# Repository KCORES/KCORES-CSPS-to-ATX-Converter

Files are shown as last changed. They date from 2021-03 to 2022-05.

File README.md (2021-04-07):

# KCORES-CSPS-to-ATX-Converter

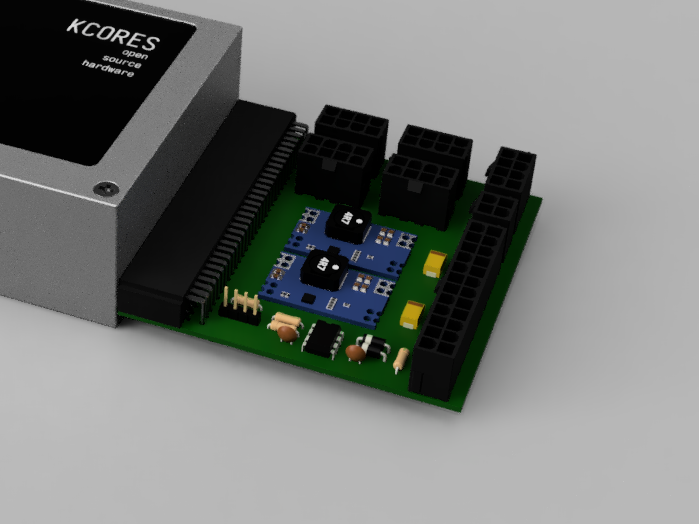
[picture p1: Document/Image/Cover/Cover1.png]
KCORES CSPS to ATX Converter


- 项目视频: [1元10瓦 垃圾佬的超级ATX电源-Youtube](https://www.youtube.com/watch?v=Dy0Jgn7Dg4A)
- KCORES 交流群: [826702309](https://jq.qq.com/?_wv=1027&k=jcr07ZYG)
- KCORES 官方网站: [KCORES.com](https://kcores.com/)
- 从零开始制作: [入门指南](Document/Getting_Started_Guide.md)

# Specification

| 12V | 5V | 3.3V  | 5VSB  |
|---|---|---|---|
|取决于CSPS| 5A | 5A | 5A |
| | 25W | 16.5W | 25W |

⚠: 5V 与 3.3V 不建议长期超过 4A 使用

## 模组接口
- 1x 24Pin 主板接口 (巨龙线序)
- 1x 4Pin IDE/SATA 硬盘接口 (联想线序)
- 5x 8Pin CPU/GPU 接口 (巨龙线序)
- 1x I2C PMBUS 控制接口

# Document

## Distinguish CSPS

KCORES CSPS to ATX Converter 可以用于引脚特征如下图所示的电源

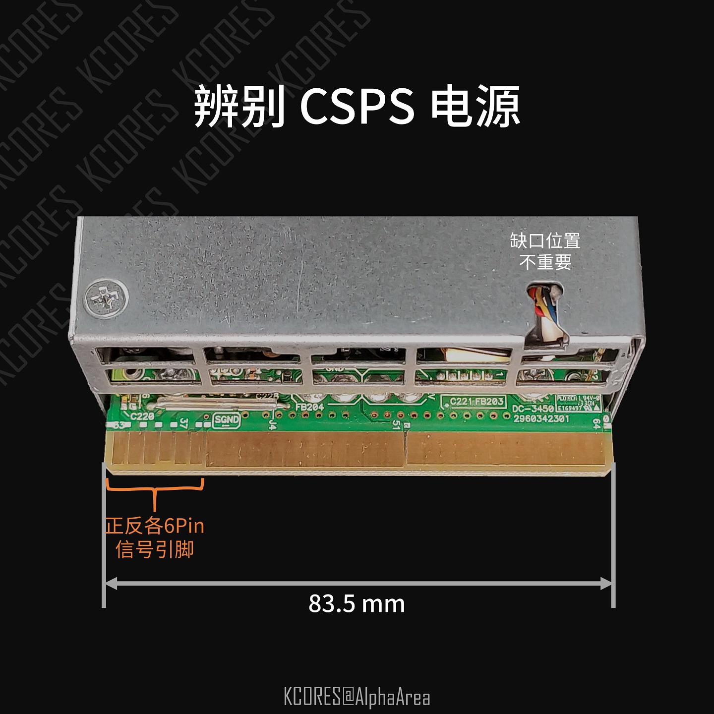
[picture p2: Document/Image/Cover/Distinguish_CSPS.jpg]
辨别 CSPS 电源


目前已知 Hewlett Packard Enterprise 与 Huawei 大量生产过 CSPS.  
不同厂家生产的 CSPS 可能外形略有不同, 但金手指必须与图示一致才可使用.  

## Getting Started Guide

- [入门指南](Document/Getting_Started_Guide.md)

# LICENSE

KCORES 许可证

# Contributor

- [@AlphaArea](https://github.com/alphaarea)
- @Ubiq
- [@karminski-牙医](https://github.com/karminski)
- [@MistyMoonR](https://github.com/MistyMoonR)

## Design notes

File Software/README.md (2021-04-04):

# Arduino Lib

# PC Host

[KCORES Link](https://github.com/KCORES/kcores-link)

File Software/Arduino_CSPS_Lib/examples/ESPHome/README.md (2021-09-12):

# ESPHome 集成

在 ESPHome 的 yaml 中增加

```yaml
esphome:
  # 原先内容
  includes:
    - CSPS/main.hpp
    - CSPS/KCORES_CSPS.h
    - CSPS/KCORES_CSPS.cpp
```

创建文件夹 `CSPS` 将 `main.hpp`, `KCORES_CSPS.h` 以及 `KCORES_CSPS.cpp` 丢进去

## 增加传感器

使用自定义传感器获取数据

```yaml
sensor:
  - platform: custom
    lambda: |-
      auto power = new CSPSPower();
      App.register_component(power);
      return {power->fan_speed, power->temp1, power->temp2, power->power_out, power->power_in, power->current_out, power->current_in, power->voltage_out, power->voltage_in};

    sensors:
    - name: "Fan Speed"
      accuracy_decimals: 0
      unit_of_measurement: RPM
    - name: "Temp 1"
      accuracy_decimals: 1
      unit_of_measurement: °C
    - name: "Temp 2"
      accuracy_decimals: 1
      unit_of_measurement: °C
    - name: "Power Out"
      accuracy_decimals: 0
      unit_of_measurement: W
    - name: "Power In"
      accuracy_decimals: 0
      unit_of_measurement: W
    - name: "Current Out"
      accuracy_decimals: 1
      unit_of_measurement: A
    - name: "Current In"
      accuracy_decimals: 1
      unit_of_measurement: A
    - name: "Voltage Out"
      accuracy_decimals: 1
      unit_of_measurement: V
    - name: "Voltage In"
      accuracy_decimals: 1
      unit_of_measurement: V
```

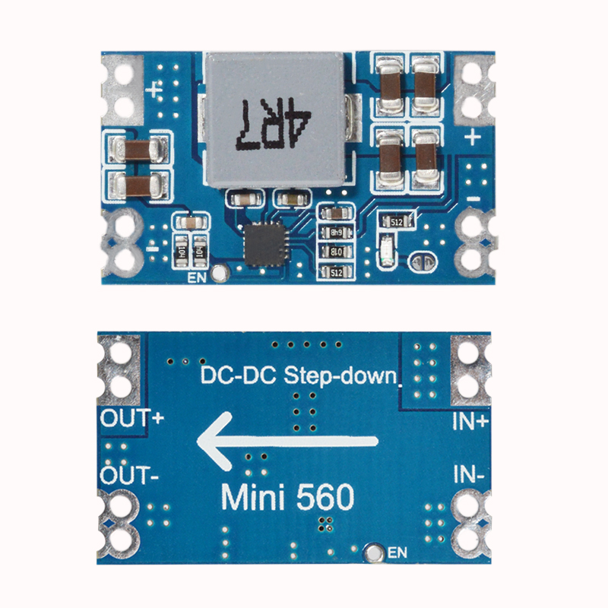
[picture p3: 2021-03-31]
Document/Datasheet/Mini 560/Mini 560.jpg

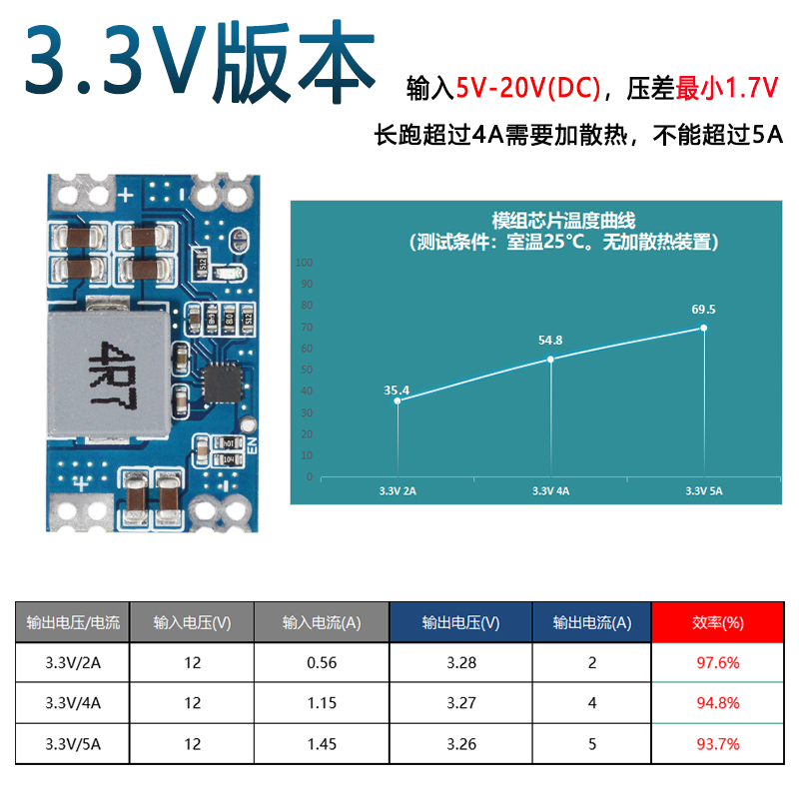
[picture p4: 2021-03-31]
Document/Datasheet/Mini 560/3.3V.jpg

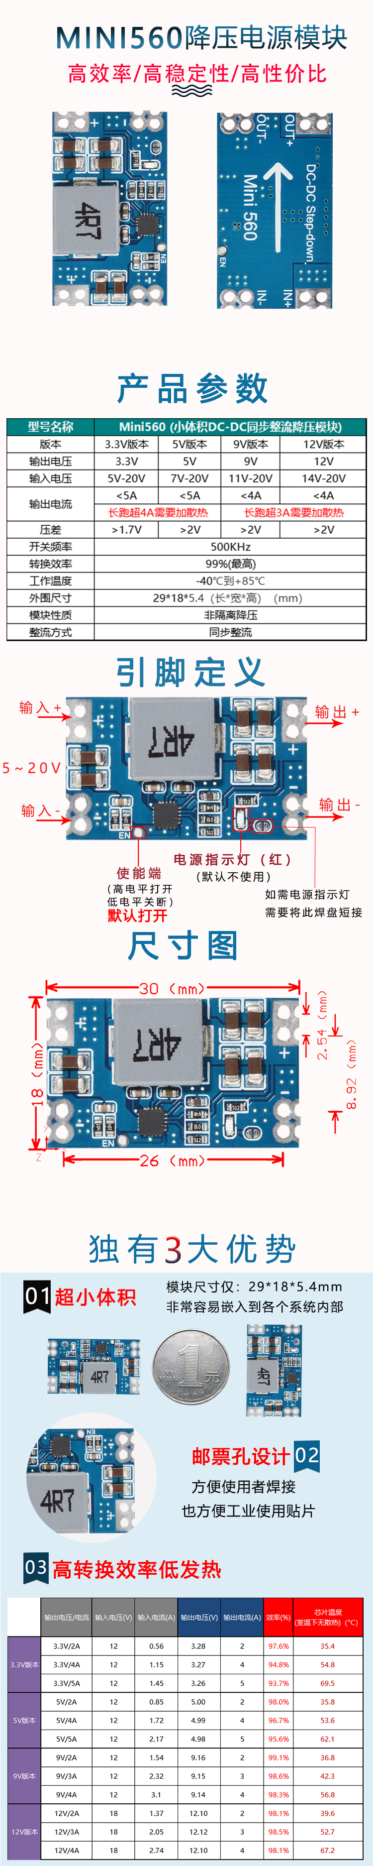
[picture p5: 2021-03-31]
Document/Datasheet/Mini 560/Mini 560-1.jpg

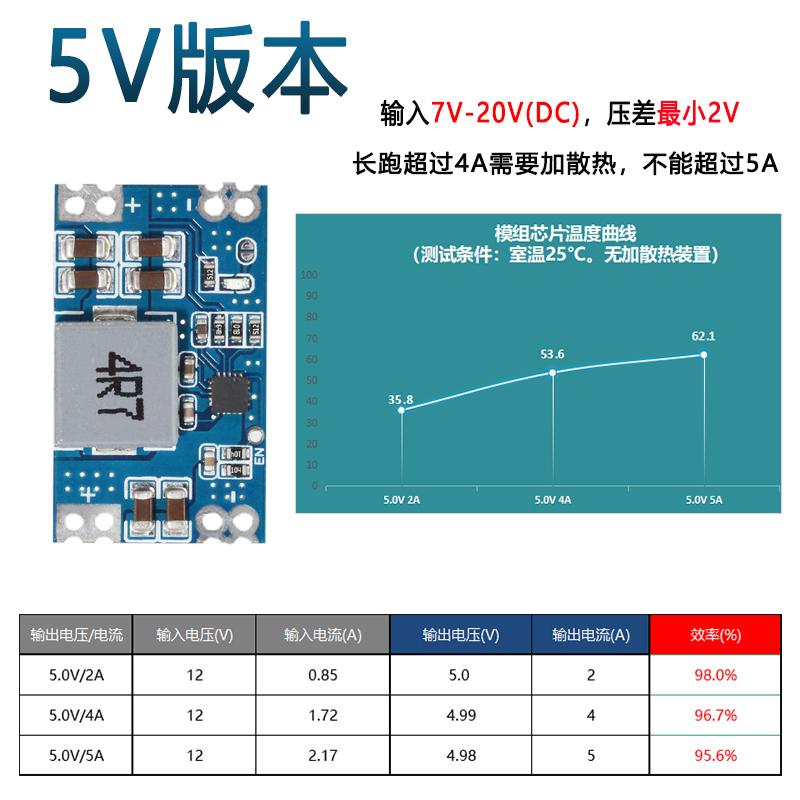
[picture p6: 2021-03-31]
Document/Datasheet/Mini 560/5V.jpg

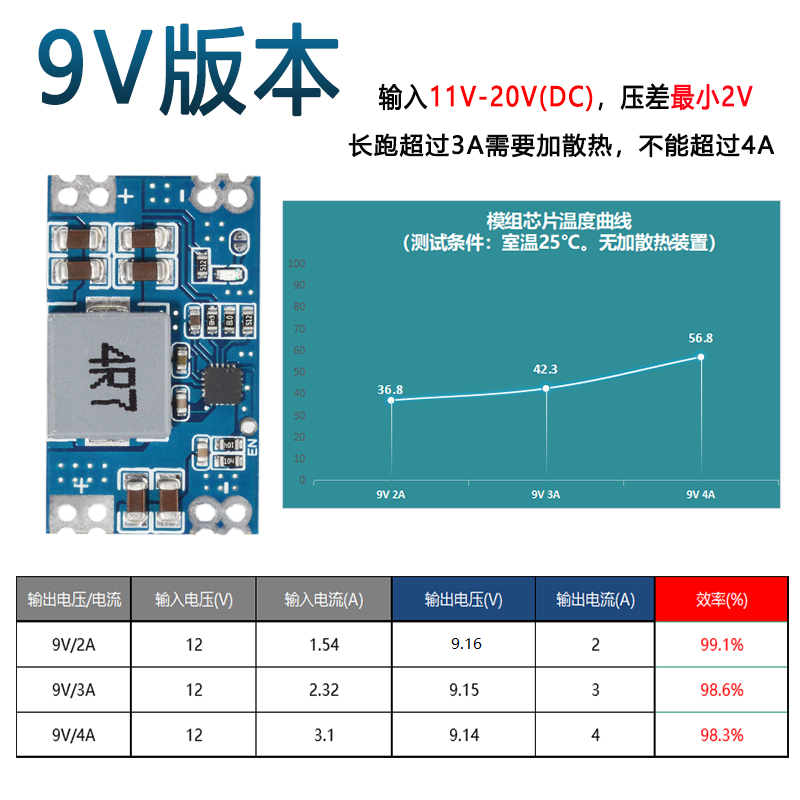
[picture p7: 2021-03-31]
Document/Datasheet/Mini 560/9V.jpg

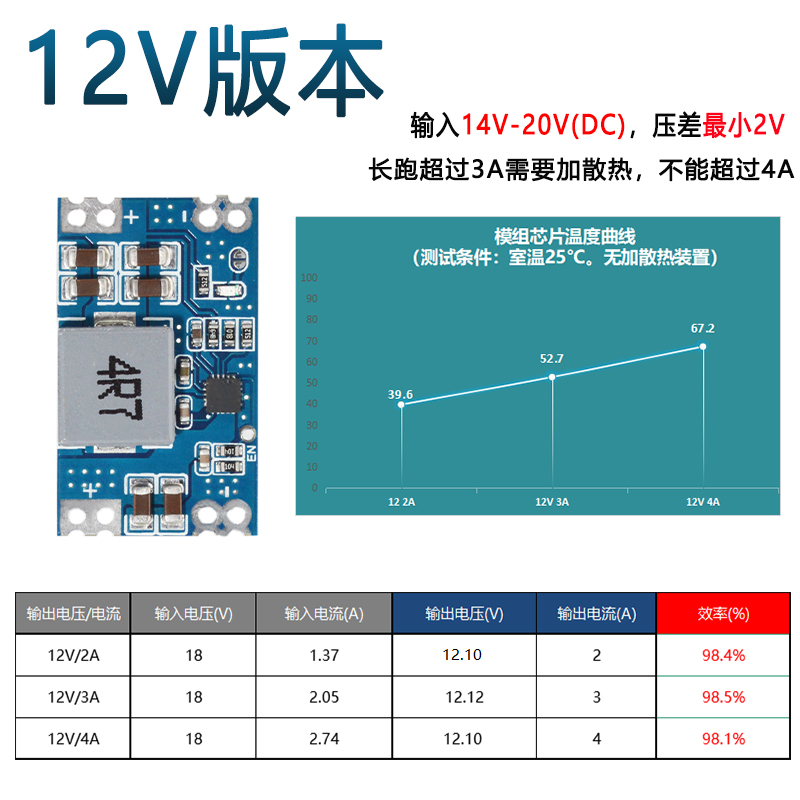
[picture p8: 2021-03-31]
Document/Datasheet/Mini 560/12V.jpg

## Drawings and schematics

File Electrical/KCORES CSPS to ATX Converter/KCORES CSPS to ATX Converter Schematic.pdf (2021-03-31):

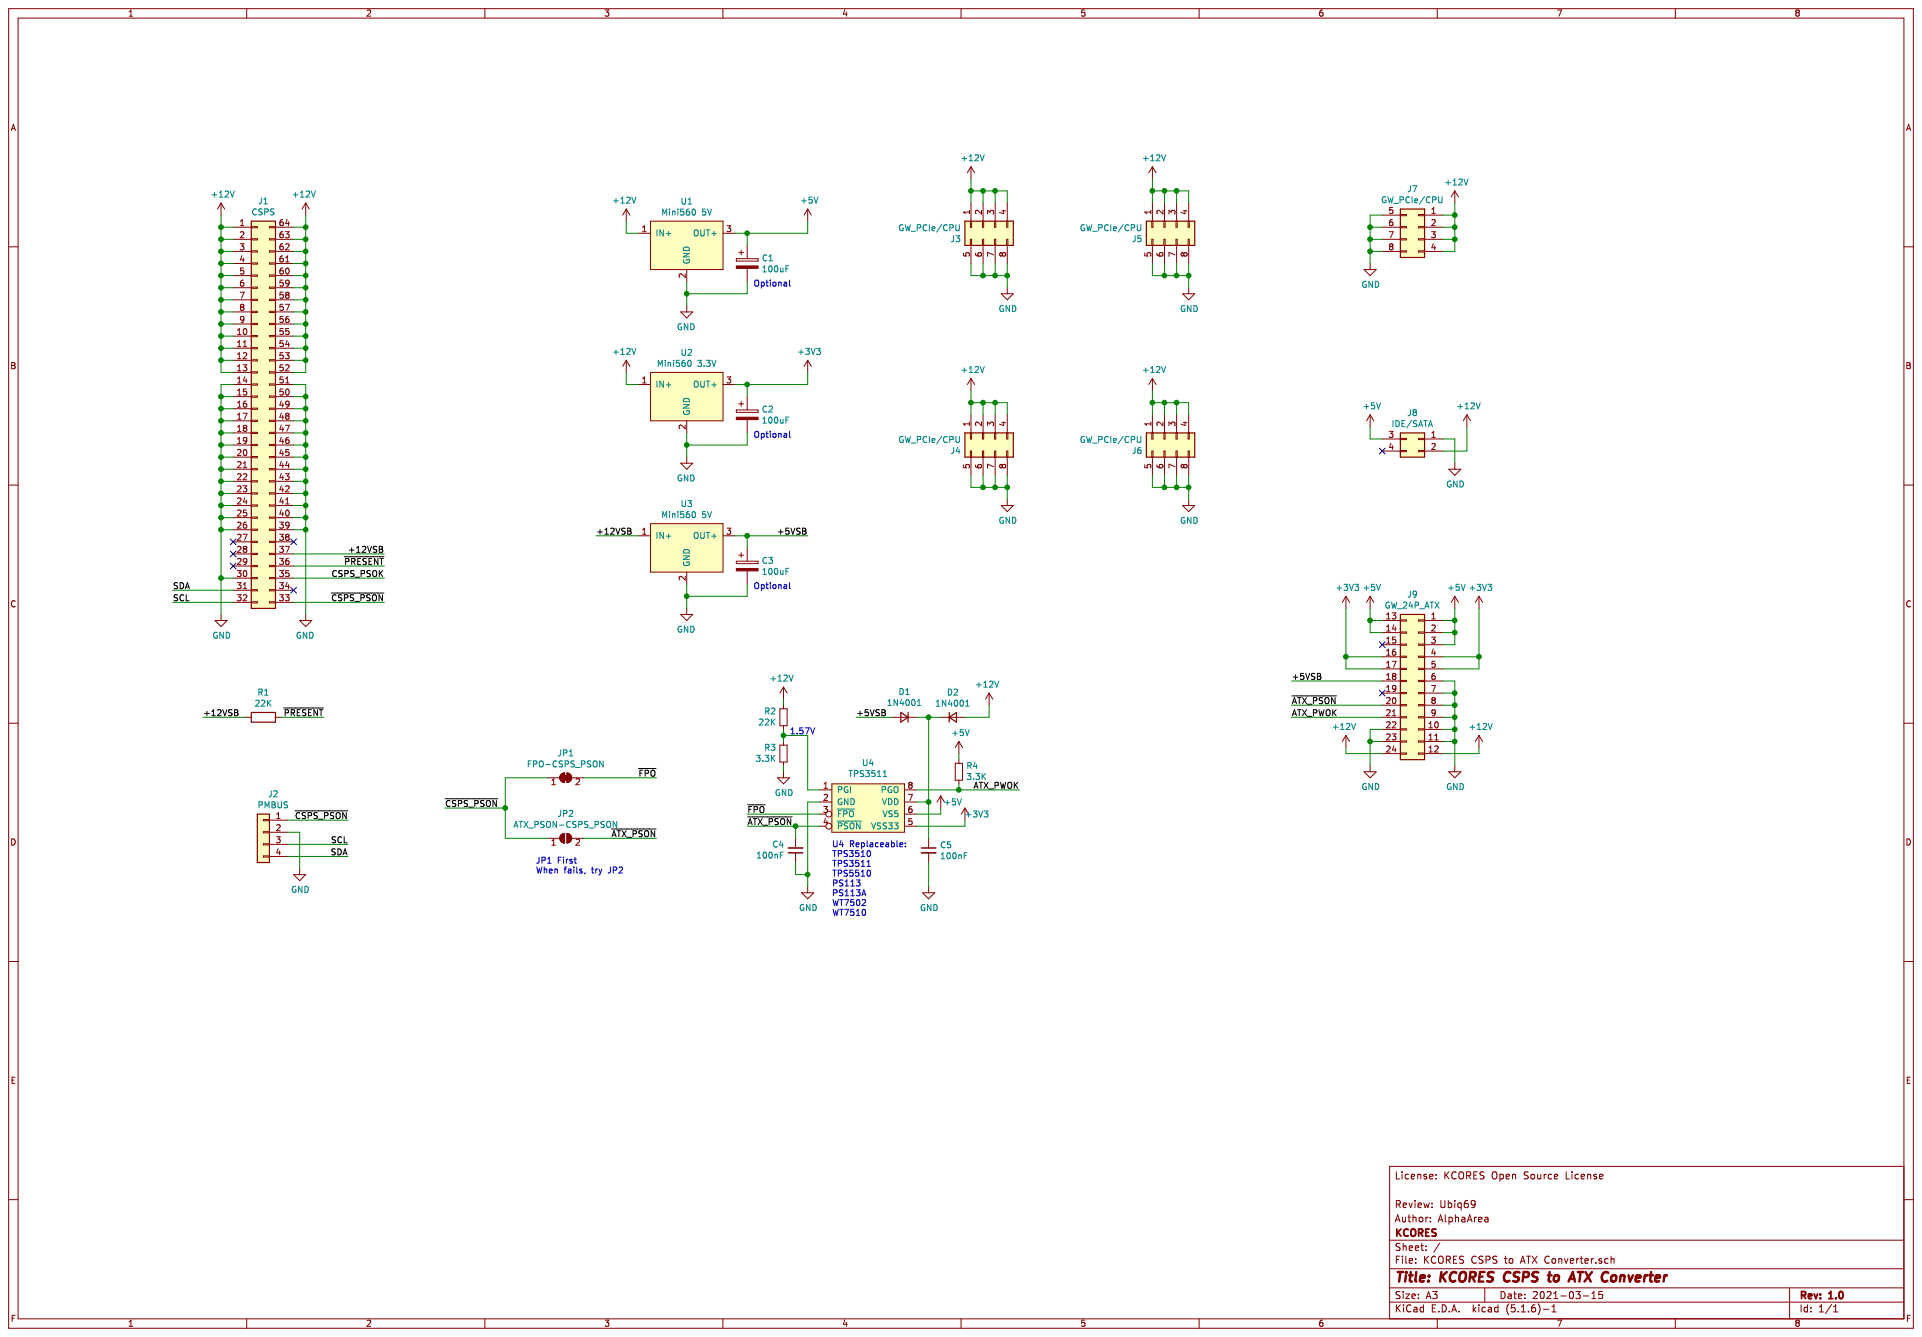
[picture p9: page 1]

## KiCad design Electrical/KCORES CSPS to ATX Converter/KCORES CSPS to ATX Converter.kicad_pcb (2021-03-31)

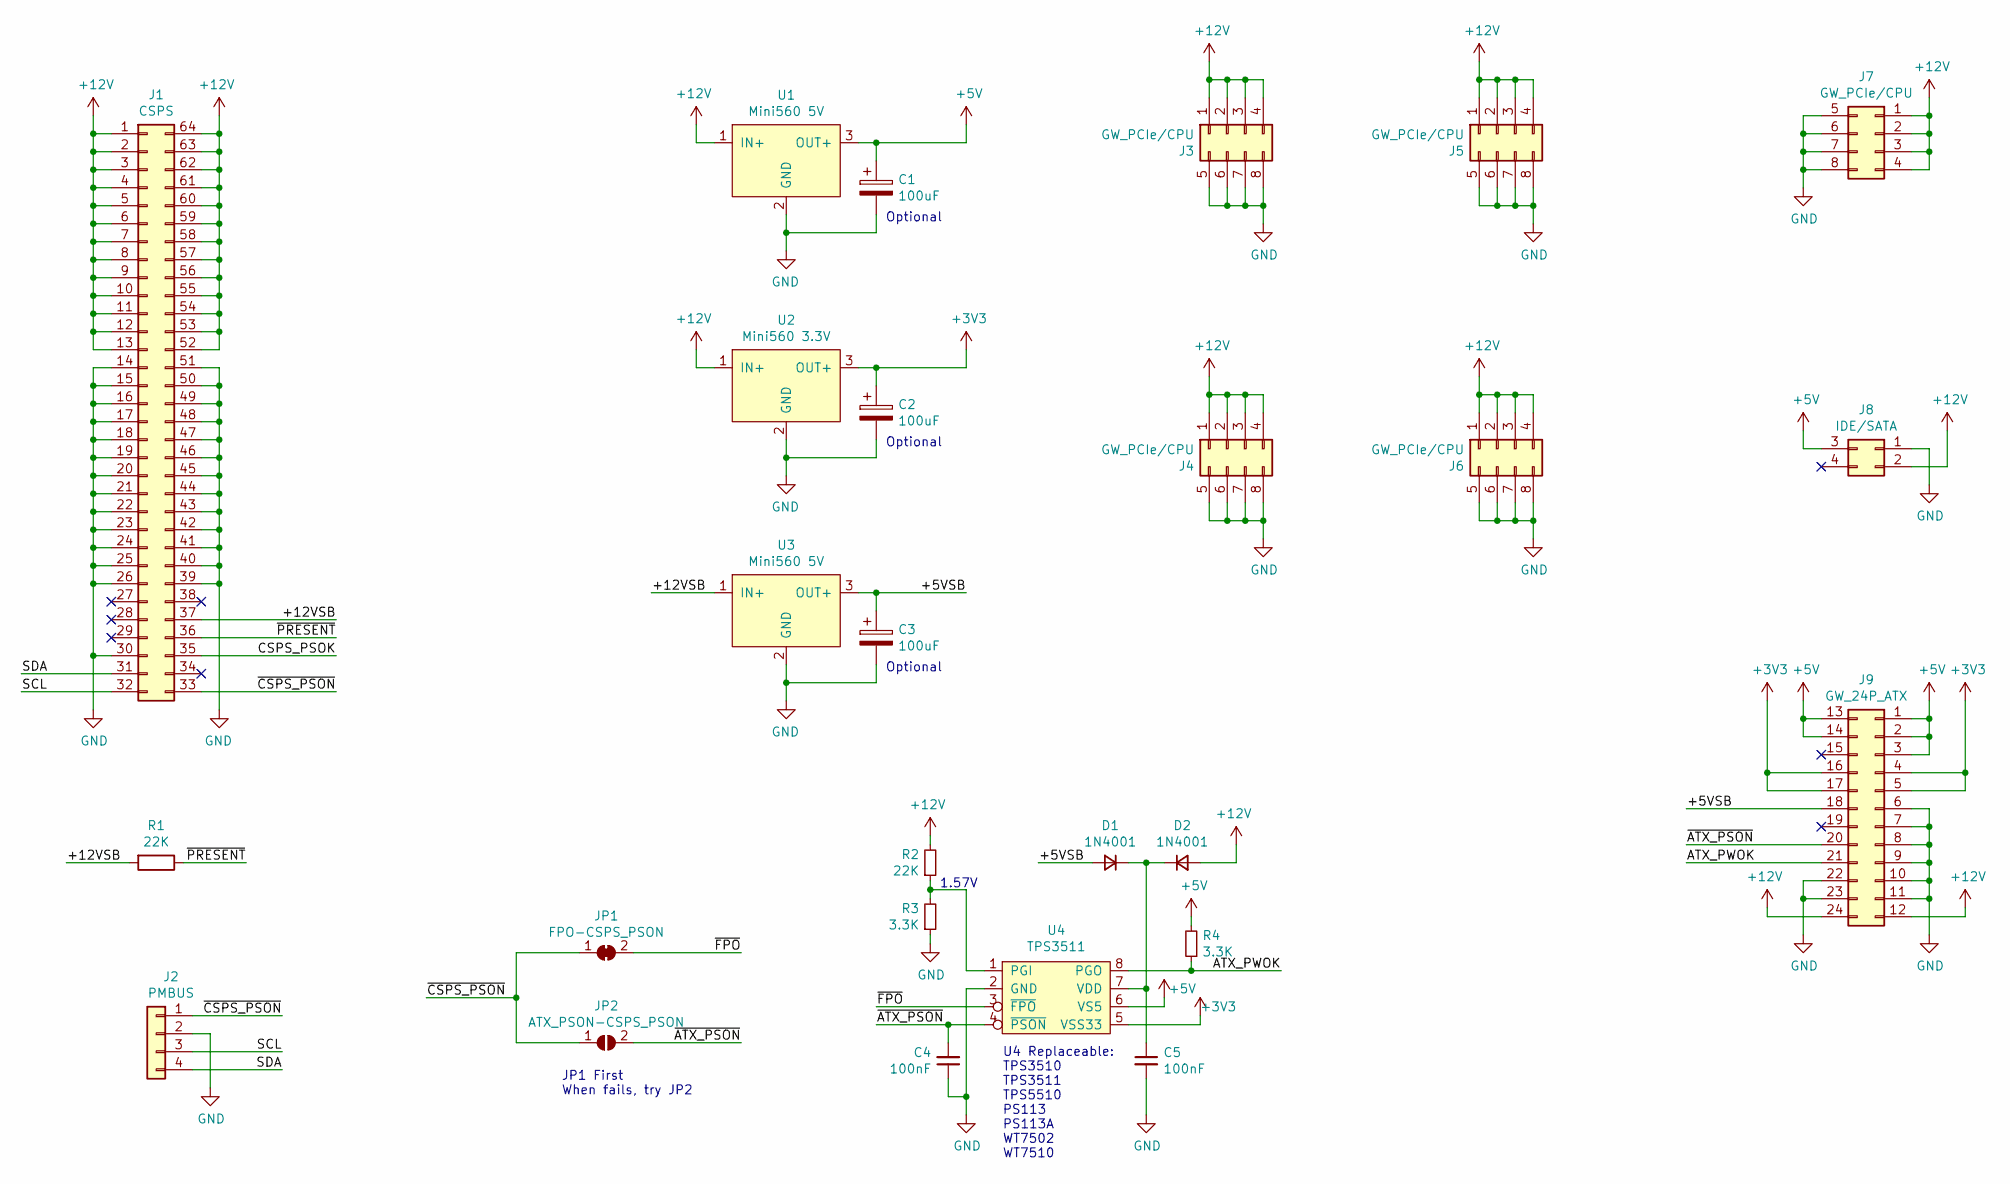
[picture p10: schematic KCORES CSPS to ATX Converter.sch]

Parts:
C1, C2, C3: 100uF; CP_EIA-7343-31_Kemet-D_Pad2.25x2.55mm_HandSolder
C4, C5: 100nF; C_Disc_D5.0mm_W2.5mm_P2.50mm
D1, D2: 1N4001; D_DO-41_SOD81_P7.62mm_Horizontal
J1: CSPS; CSPS_64P_2.54mm
J2: PMBUS; PinHeader_1x04_P2.54mm_Vertical
J3, J4, J5, J6, J7: GW_PCIe/CPU; ATX_8Pin_P4.20mm_Vertical_4.20mm
J8: IDE/SATA; ATX_4Pin_P4.20mm_Vertical_4.20mm
J9: GW_24P_ATX; ATX_24Pin_P4.20mm_Vertical_4.20mm
JP1: FPO-CSPS_PSON; SolderJumper-2_P1.3mm_Bridged_RoundedPad1.0x1.5mm
JP2: ATX_PSON-CSPS_PSON; SolderJumper-2_P1.3mm_Open_RoundedPad1.0x1.5mm
R1, R2: 22K; R_Axial_DIN0207_L6.3mm_D2.5mm_P7.62mm_Horizontal
R3, R4: 3.3K; R_Axial_DIN0207_L6.3mm_D2.5mm_P7.62mm_Horizontal
U1, U3: Mini560 5V; Converter_DCDC_Mini_560
U2: Mini560 3.3V; Converter_DCDC_Mini_560
U4: TPS3511; DIP-8_W7.62mm

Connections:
+3V3: C2.1, J9.4, J9.5, J9.16, J9.17, U2.3 (OUT+), U4.5 (VSS33)
+5V: C1.1, J8.3, J9.1, J9.2, J9.3, J9.13, J9.14, R4.2, U1.3 (OUT+), U4.6 (VS5)
+12V: D2.2 (A), J1.1, J1.2, J1.3, J1.4, J1.5, J1.6, J1.7, J1.8, J1.9, J1.10, J1.11, J1.12, J1.13, J1.52, J1.53, J1.54, J1.55, J1.56, J1.57, J1.58, J1.59, J1.60, J1.61, J1.62, J1.63, J1.64, J3.1, J3.2, J3.3, J3.4, J4.1, J4.2, J4.3, J4.4, J5.1, J5.2, J5.3, J5.4, J6.1, J6.2, J6.3, J6.4, J7.1, J7.2, J7.3, J7.4, J8.2, J9.12, J9.24, R2.2, U1.1 (IN+), U2.1 (IN+)
/+5VSB: C3.1, D1.2 (A), J9.18, U3.3 (OUT+)
/+12VSB: J1.37, R1.2, U3.1 (IN+)
/ATX_PWOK: J9.21, R4.1, U4.8 (PGO)
/CSPS_PSOK: J1.35
/SCL: J1.32, J2.3
/SDA: J1.31, J2.4
/~ATX_PSON: C4.2, J9.20, JP2.2 (B), U4.4 (~PSON)
/~CSPS_PSON: J1.33, J2.1, JP1.1 (A), JP2.1 (A)
/~FPO: JP1.2 (B), U4.3 (~FPO)
/~PRESENT: J1.36, R1.1
GND: C1.2, C2.2, C3.2, C4.1, C5.2, J1.14, J1.15, J1.16, J1.17, J1.18, J1.19, J1.20, J1.21, J1.22, J1.23, J1.24, J1.25, J1.26, J1.30, J1.39, J1.40, J1.41, J1.42, J1.43, J1.44, J1.45, J1.46, J1.47, J1.48, J1.49, J1.50, J1.51, J2.2, J3.5, J3.6, J3.7, J3.8, J4.5, J4.6, J4.7, J4.8, J5.5, J5.6, J5.7, J5.8, J6.5, J6.6, J6.7, J6.8, J7.5, J7.6, J7.7, J7.8, J8.1, J9.6, J9.7, J9.8, J9.9, J9.10, J9.11, J9.22, J9.23, R3.1, U1.2 (GND), U2.2 (GND), U3.2 (GND), U4.2 (GND)
unnamed: C5.1, D1.1 (K), D2.1 (K), U4.7 (VDD)
unnamed: R2.1, R3.2, U4.1 (PGI)

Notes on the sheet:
Optional
1.57V
JP1 First When fails, try JP2
U4 Replaceable: TPS3510 TPS3511 TPS5510 PS113 PS113A WT7502 WT7510

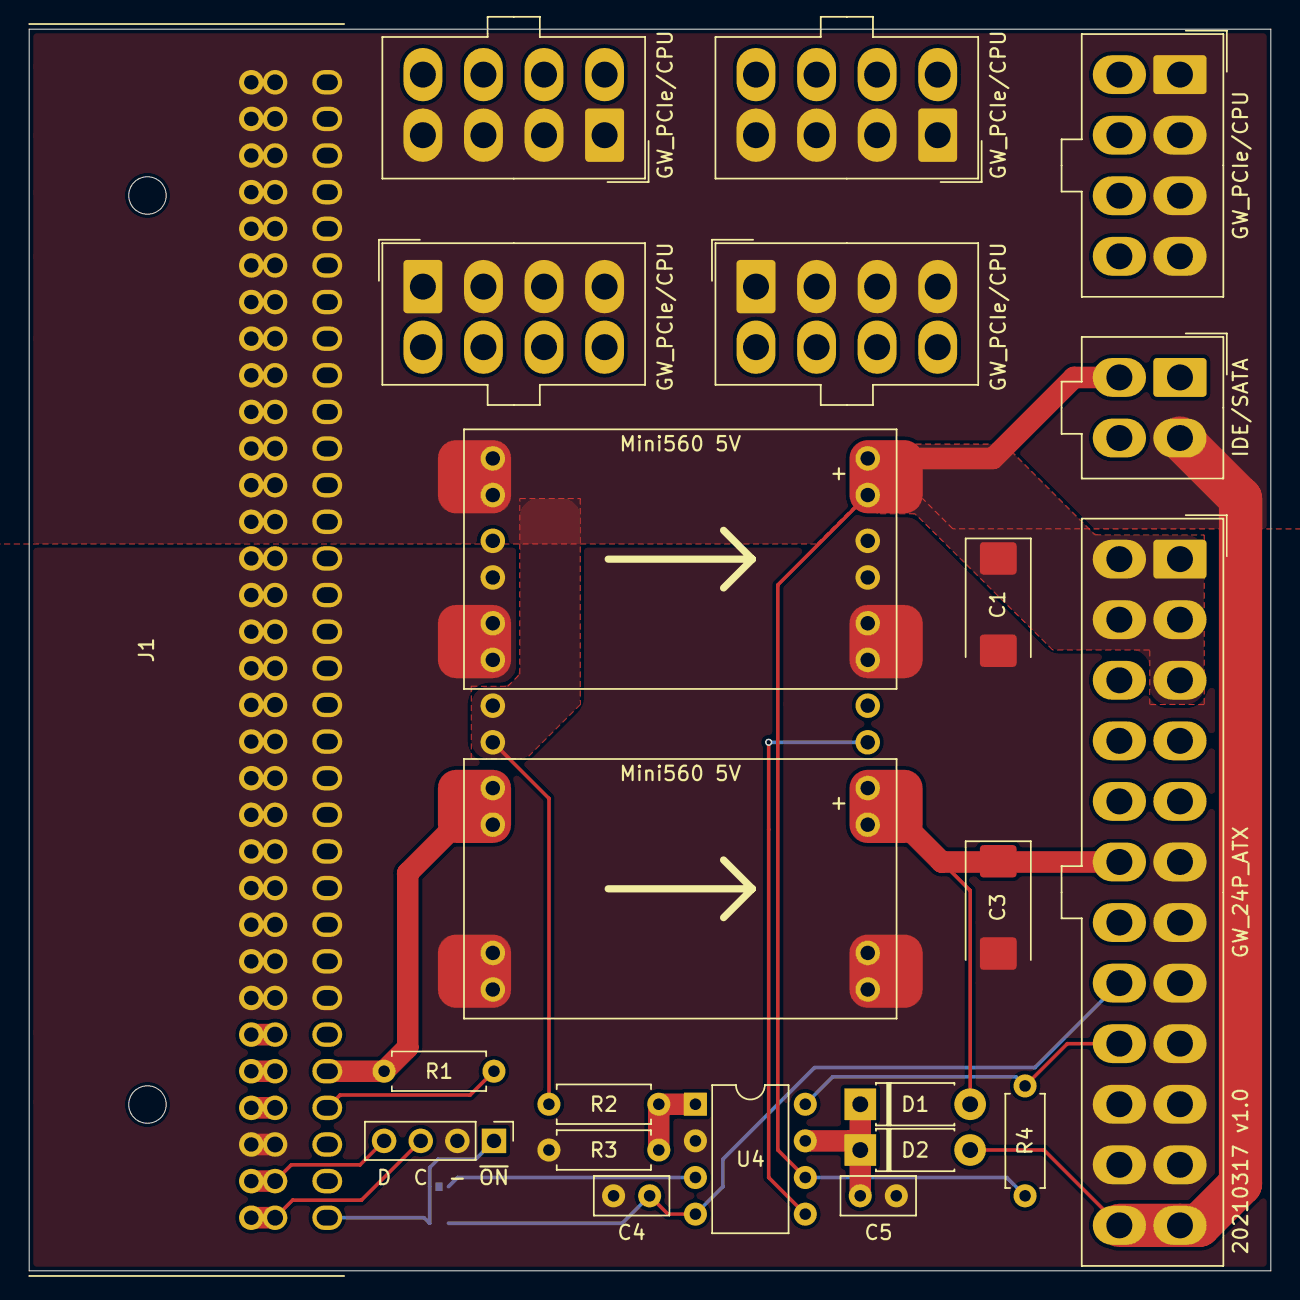
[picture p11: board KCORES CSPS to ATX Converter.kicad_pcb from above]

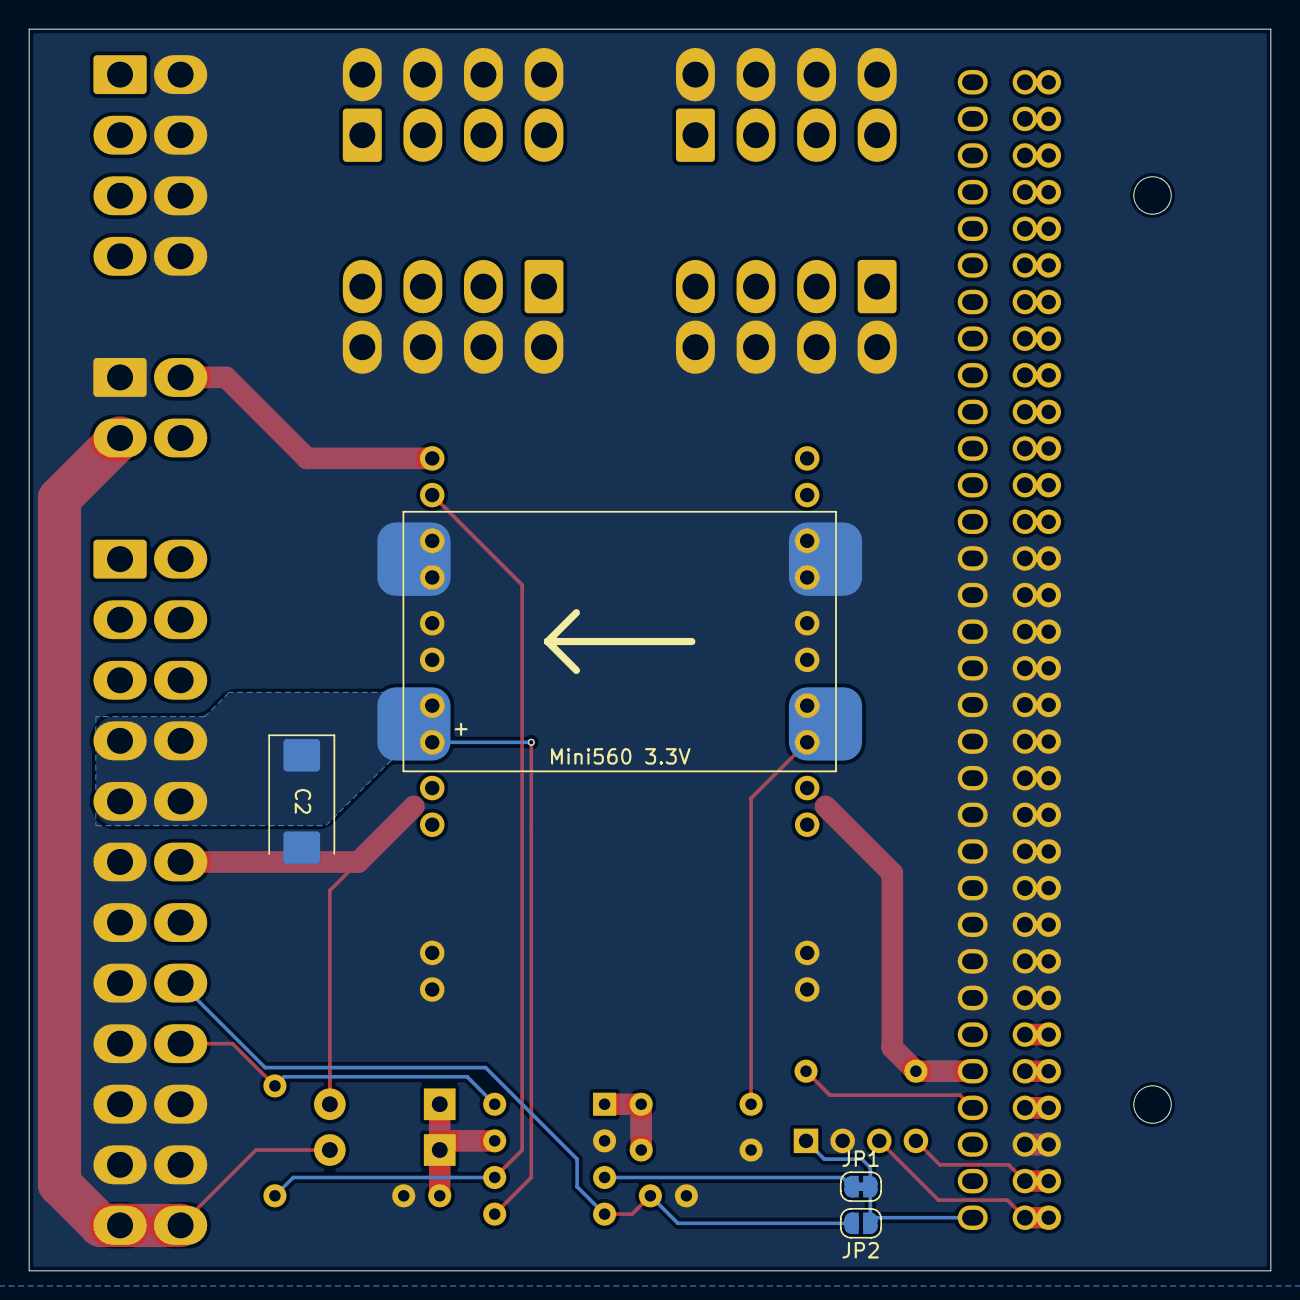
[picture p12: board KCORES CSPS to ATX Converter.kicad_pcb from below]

Board: 2 copper layers, 86.1 x 86.1 mm, 26 parts (4 on the bottom side), 15 nets.

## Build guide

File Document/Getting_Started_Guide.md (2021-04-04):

# 准备

1. 下载 [Releases](https://github.com/KCORES/KCORES-CSPS-to-ATX-Converter/releases) 中最新发布版的 Gerber 文件包与 BOM 表格.  
    - Gerber 文件: 用于发送给 PCB 工厂生产 PCB
    - BOM 表格: 购买元器件

## BOM 说明

1. 钽电容选配, 不焊接钽电容不影响转接板性能
2. 5566 连接器 (ATX 插座) 分实心针与空心针两种，互不兼容, 本项目全部使用实心针
3. Mini560 模块上没有电压标注, 保留包装，切勿弄混
4. 支持两种 CSPS 连接器
    - FCI 10053363-200LF: 进口连接器, 价格较贵, 允许通过较大电流, 插拔手感较好
    - WingTAT S-64M-2.54-5: 廉价连接器, 仅建议搭配 460W 与 750W 电源时使用
5. U4 监控芯片有多种替换件, 建议选择 TPS3510P

## 安全注意

- 不要随意拆开 CSPS 外壳, 即使断电后 PFC 电容内可能仍有高压
- 禁止带电插拔 CSPS 与转接板, 必须先断开市电, 待 CSPS 风扇停转后再插拔转接板

# 焊接

## 焊接一

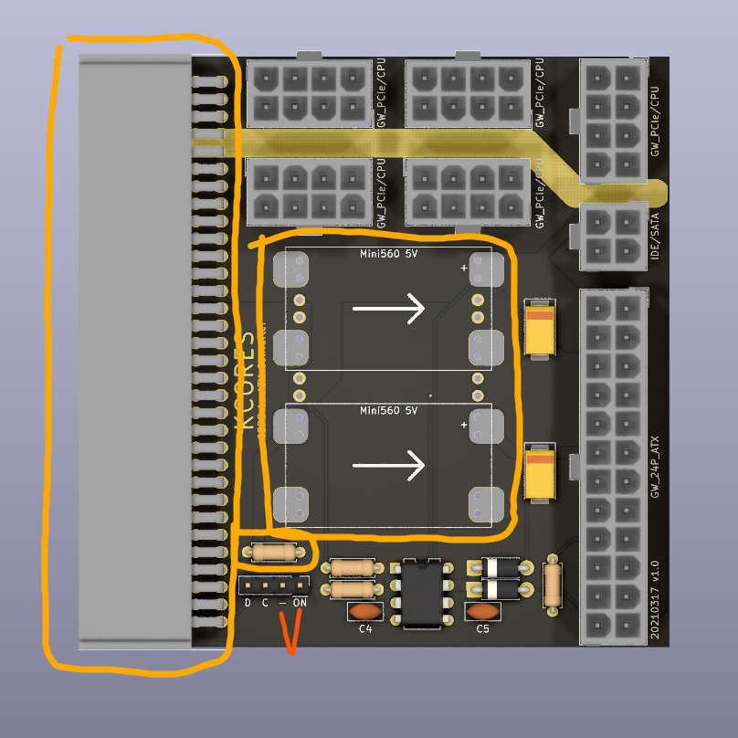
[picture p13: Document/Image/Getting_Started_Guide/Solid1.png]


- CSPS 连接器
- 所有降压模块
- R1 识别电阻

完成焊接后, 插入电源并通电, 短接橙色线画出的 GND 与 ~ON 引脚开机, CSPS 尾部电源指示灯变绿, 使用万用表测量各输出口电压是否正常

- 若无 12V 输出, 请检查主输出是否短路, R1 识别电阻是否焊接错误
- 若无 5V/3.3V 输出, 请检查对应的 DCDC 模块

## 焊接二

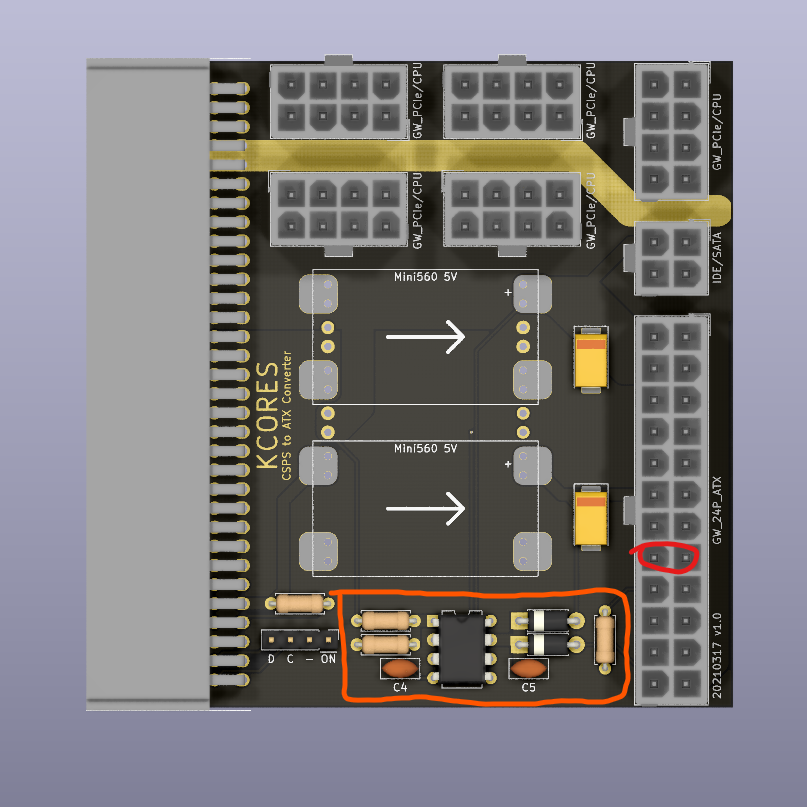
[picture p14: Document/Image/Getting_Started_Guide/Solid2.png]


- ATX 控制电路
- 测试 ATX 控制 IC
- 焊接 ATX 控制 IC

⚠注意: ATX 控制 IC 极易受静电损坏, 插上检测工作正常再焊接, 或直接焊接 DIP-8 插座以便更换 IC

完成后, 短接红圈处 ATX 开机引脚, 电源应启动且各路输出电压正常

## 焊接三

完成其它接口焊接, 注意封装方向,

# Enjoy Yourself

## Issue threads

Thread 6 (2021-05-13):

小改了一下arduino程序在stm32f103c8t6上跑 (使用stm32duino)

maz-1, 2021-05-13:
KCORES_CSPS.cpp改三个地方就成：
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
前两个是改掉i2c引脚，避免和集成的的microusb接口冲突造成虚拟串口不能用
后一个是因为stm32是32位而arduino uno是8位

stm32的优点就是体积小，曾经很便宜（前年十几块买的，就是最近元器件缺货涨到30了，有的店家推荐用CH32F103C8T6替代，功能和引脚基本一致），然后自带两个i2c，能同时连更多设备

maz-1, 2021-05-17:
完整程序：https://github.com/maz-1/CSPS_ATX_Backplate/tree/master/Arduino/KCORES_Link_V1

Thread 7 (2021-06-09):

3.3v和5v输出是否考虑加个自恢复保险

chraac, 2021-06-09:
RT，5v和3.3v的最大输出分别为10a和5a，对比其他电源是偏小的，然后某些2.5mm机械硬盘会需要5v供电，有没有可能瞬时电流过大导致烧坏dc dc模块？是否加个自恢复保险能避免这个问题？

alphaarea, 2021-06-10:
DC-DC模块自带打嗝保护，任意一路保护后ATX监控IC会关闭主输出，安全上没有问题，不需要自恢复保险。

chraac, 2021-06-10:
> DC-DC模块自带打嗝保护，任意一路保护后ATX监控IC会关闭主输出，安全上没有问题，不需要自恢复保险

Closed 2021-06-10.

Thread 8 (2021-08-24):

华为的只有82mm 也能和这个兼容吗?

Sky-lark, 2021-08-24:

alphaarea, 2021-09-01:
请提供具体型号或图片

2603king, 2021-12-08:
大佬华为的pac系列能用吗？比如pac“XXX” S12 “XX”

alphaarea, 2021-12-08:
> 大佬华为的pac系列能用吗？比如pac“XXX” S12 “XX”

https://github.com/KCORES/KCORES-CSPS-to-ATX-Converter#distinguish-csps

2603king, 2021-12-08:
> > 大佬华为的pac系列能用吗？比如PAC“XXX”S12“XX”
>
> [Https://github.com/KCORES/KCORES-CSPS-to-ATX-Converter#distinguish-csps](https://github.com/KCORES/KCORES-CSPS-to-ATX-Converter#distinguish-csps)

就最左边要多几根，那看来是用不了了只能从新买个

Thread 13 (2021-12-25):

请问一个，如果我有CRPS电的是规格书，可以看接口定义，是不是也可以用咱们这个PCB？

openxbmc, 2021-12-25:
RT,有几个长城的1200W CRPS 第5针短一点 跟惠普或者光宝的不一样 打算自己改一下

alphaarea, 2021-12-28:
https://github.com/KCORES/KCORES-CSPS-to-ATX-Converter#distinguish-csps

openxbmc, 2021-12-29:
>

是的 跟图片不同，图片是第四针短，我这是第五针，目前我已经下载好电路图准备改板了

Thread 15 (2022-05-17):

exit status 1 'class HardwareSerial' has no member named 'printf'; did you mean 'print'?  什么原因，怎么解决？

SDRC43, 2022-05-17:
验证时总是提示
exit status 1
'class HardwareSerial' has no member named 'printf'; did you mean 'print'?
是什么原因

SDRC43, 2022-05-17:
KCORES_CSPS.cpp:90:18: error: 'class HardwareSerial' has no member named 'printf'; did you mean 'print'?
           Serial.printf("CSPS::readCSPSword() Missmatch checksum. addr: 0x%02x, chk: 0x%02x\n", dataAddr, cs);
                  ^~~~~~
                  print
exit status 1
'class HardwareSerial' has no member named 'printf'; did you mean 'print'?

alphaarea, 2022-05-20:
把有printf的都整个注释掉

SDRC43, 2022-05-23:
收到，谢谢，已按此解决

在 2022-05-20 16:07:50，"Alpha Area" ***@***.***> 写道：

把有printf的都整个注释掉

—
Reply to this email directly, view it on GitHub, or unsubscribe.
You are receiving this because you authored the thread.Message ID: ***@***.***>

Closed 2022-05-20.

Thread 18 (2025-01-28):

为什么ESP32S3/C3都无法获取I2C数据？换上8266就行？

bbluvgg, 2025-01-28:
我DIY一项硬件项目集成了众多功能，但ESP32S3始终无法与CSPS电源I2C通信，反复检查无果（有5V→3.3V，引脚无误），换了C3也不行，但用8266就能马上识别，是不是3个声明文件有8266限制性代码？如何修改？

BG8HQE, 2025-02-27:
我用的ESPHOME，CPU用ESP32C3，也是扫描不到I２C设备了，８２６６和ESP32都可以

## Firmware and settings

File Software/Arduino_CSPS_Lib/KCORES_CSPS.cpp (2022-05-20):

/*!
 * @file KCORES_CSPS.cpp
 *
 * This is a library for the CSPS PMBUS
 * Written by AlphaArea
 *
 * GPL license, all text here must be included in any redistribution.
 *
 */

#include "KCORES_CSPS.h"

CSPS::CSPS(byte CSPS_addr)
{
  _CSPS_addr = CSPS_addr;
  _ROM_addr = CSPS_addr - 8;
  _CSPS_READ_CHECKSUM = false;
  Wire.begin();
}

CSPS::CSPS(byte CSPS_addr, byte ROM_addr)
{
  _CSPS_addr = CSPS_addr;
  _ROM_addr = ROM_addr;
  _CSPS_READ_CHECKSUM = false;
  Wire.begin();
}


CSPS::CSPS(byte CSPS_addr, byte ROM_addr, bool ENABLE_CHECKSUM)
{
  _CSPS_addr = CSPS_addr;
  _ROM_addr = ROM_addr;
  _CSPS_READ_CHECKSUM = ENABLE_CHECKSUM;
  Wire.begin();
}

String CSPS::getROM(byte addr, byte len)
{
  String rec;
  for (byte n = 0; n < len; n++)
    rec.concat((char)readROM(addr + n));
  return rec;
}

byte CSPS::readROM(byte dataAddr)
{
  byte rec = 0x00;
  Wire.beginTransmission(_ROM_addr);
  Wire.write(dataAddr);
  Wire.endTransmission();
  Wire.requestFrom(_ROM_addr, 1);
  if (Wire.available())
    rec = Wire.read();
  return rec;
}

// Calclate checksum read from PM BUS
uint8_t checksum(uint32_t data) {
    uint8_t cs = 0;
    cs += ((data & 0xFF0000) >> 16);
    cs += ((data & 0xFF00) >> 8);
    cs += (data & 0xFF);

    cs = ((0xFF - cs) + 1) & 0xFF;
    return cs;
}

// uint32_t to int32_t is safe for CSPS Word (3 bytes)
int32_t CSPS::_readCSPSword(byte dataAddr)
{
  byte regCS = ((0xFF - (dataAddr + (_CSPS_addr << 1))) + 1) & 0xFF;
  uint32_t rec = 0xFFFF;
  Wire.beginTransmission(_CSPS_addr);
  Wire.write(dataAddr);
  Wire.write(regCS);
  Wire.endTransmission();
  Wire.requestFrom(_CSPS_addr, 3);
  if (Wire.available())
  {
    rec = Wire.read();
    rec |= Wire.read() << 8;
    rec |= Wire.read() << 16;

    if (_CSPS_READ_CHECKSUM) {
      uint8_t cs = checksum(rec);

      if (cs != 0) {
#ifdef CSPS_ERROR_TO_SERIAL
        // Output error to serial
        if (Serial) {
          char buf[70];

          snprintf(buf, 70, "CSPS::readCSPSword() Missmatch checksum. addr: 0x%02x, chk: 0x%02x\r\n", dataAddr, cs);
          Serial.print(buf);
        }
#endif
        return -1;
      }

      // Don't return checksum
      return rec & 0x00FFFF;
    }
    return rec;
  }
  else
    return 0;
}

uint32_t CSPS::readCSPSword(byte dataAddr) {
  // Re-try 3 times

  for(int i = 0; i < 3; i++) {
    int32_t data = _readCSPSword(dataAddr);

    if (data != -1) {
      return data;
    }
  }

  return 0;
}

void CSPS::writeCSPSword(byte dataAddr, unsigned int data)
{
  byte valLSB = lowByte(data),
       valMSB = highByte(data);
  uint8_t cs = (_CSPS_addr << 1) + dataAddr + valLSB + valMSB;
  uint8_t regCS = ((0xFF - cs) + 1) & 0xff;
  //the checksum is the 'secret sauce'
  //writeInts = [reg, valLSB, valMSB, regCS]; //write these 4 bytes to i2c
  Wire.beginTransmission(_CSPS_addr);
  Wire.write(dataAddr);
  Wire.write(valLSB);
  Wire.write(valMSB);
  Wire.write(regCS);
  Wire.endTransmission();
}

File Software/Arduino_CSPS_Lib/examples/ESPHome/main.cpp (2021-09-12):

#include "KCORES_CSPS.h"
#include "esphome.h"

CSPS PowerSupply(0x5F, 0x57, true);

class CSPSPower : public PollingComponent {
  public:
    Sensor *fan_speed = new Sensor();
    Sensor *temp1 = new Sensor();
    Sensor *temp2 = new Sensor();
    Sensor *power_in = new Sensor();
    Sensor *power_out = new Sensor();
    Sensor *current_out = new Sensor();
    Sensor *current_in = new Sensor();
    Sensor *voltage_out = new Sensor();
    Sensor *voltage_in = new Sensor();

    CSPSPower(): PollingComponent(15000) { }

    void setup() override {
      Wire.setClock(10000);

      ESP_LOGD("Power Supply", "Spare Part No: %s", PowerSupply.getSPN().c_str());
      ESP_LOGD("Power Supply", "Manufacture Date: %s", PowerSupply.getMFG().c_str());
      ESP_LOGD("Power Supply", "Manufacturer: %s", PowerSupply.getMFR().c_str());
      ESP_LOGD("Power Supply", "Power Name: %s", PowerSupply.getName().c_str());
      ESP_LOGD("Power Supply", "Option Kit No: %s", PowerSupply.getOKN().c_str());
      ESP_LOGD("Power Supply", "CT Date Codes: %s", PowerSupply.getCT().c_str());
    }

    void update() override {
      // float current_out = PowerSupply.getOutputCurrent() / 256 / 256 / 256;

      fan_speed->publish_state(PowerSupply.getFanRPM());
      temp1->publish_state(PowerSupply.getTemp1());
      temp2->publish_state(PowerSupply.getTemp2());
      power_out->publish_state(PowerSupply.getOutputPower());
      power_in->publish_state(PowerSupply.getInputPower());
      current_out->publish_state(PowerSupply.getOutputCurrent());
      current_in->publish_state(PowerSupply.getInputCurrent());
      voltage_out->publish_state(PowerSupply.getOutputVoltage());
      voltage_in->publish_state(PowerSupply.getInputVoltage());
    }
};

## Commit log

2021-04-04 update Arduino lib
2021-09-08 feat: pmbus read checksum fix, add esphome example
    [KCORES_CSPS.cpp, main.cpp]
2021-09-08 docs(esphome): update sensors example
2021-09-16 fix: Serial.printf not exist on some environment
    [KCORES_CSPS.cpp]

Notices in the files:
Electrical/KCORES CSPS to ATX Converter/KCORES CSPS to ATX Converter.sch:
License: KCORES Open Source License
